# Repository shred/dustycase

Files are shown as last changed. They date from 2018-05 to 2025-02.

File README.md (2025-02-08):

# Particulates Sensor Case

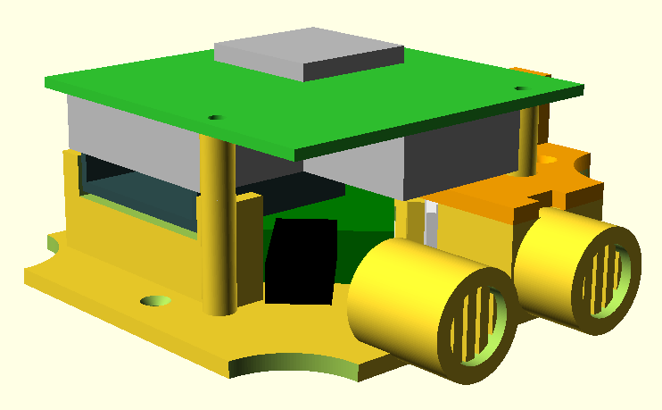
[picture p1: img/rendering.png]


This is a frame for a [luftdaten.info](https://luftdaten.info) compatible particulates sensor.

The original sensor is housed in drain pipes, which is cheap, but also looks quite like that. ;-)

This construction uses an OBO Bettermann T60 junction box, which looks nicer, and is also UV resistant and IP66 water protected. All components are mounted on the printed frame and fixed inside the junction box. Two wind pipes at the bottom of the box allow air flow. A printed tunnel guides the inlet air to the sensor, so there is no need for a hose. Grilles in the wind pipes keep insects from crawling into the box.

A DHT22 temperature and humidity sensor is required for this construction. It is placed at the wall of the inlet air tunnel, so it is protected from rain, but still exposed to the outside air. There is a space for an optional BMP180 air pressure sensor.

Also see the [project page at the PrusaPrinters community](https://www.prusaprinters.org/prints/79784-particulates-sensor-case) for more photos and downloadable STL files.

## Usage

The [frame.scad](./frame.scad) file contains the source code of the construction. You can edit it with [OpenSCAD](http://www.openscad.org/).

## Contribute

* Fork the [Source code at Codeberg](https://codeberg.org/shred/dustycase). Feel free to send pull requests.
* Found a bug? [File a bug report!](https://codeberg.org/shred/dustycase/issues)

## License

This project is licensed under the [Creative Commons - Attribution - Non-Commercial - Share Alike](http://creativecommons.org/licenses/by-nc-sa/3.0/) license.

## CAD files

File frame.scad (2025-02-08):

/*
 * Frame for mounting an SDS011 dust sensor and a NodeMCU into an
 * OBO Bettermann T60 box.
 *
 * (C) 2018 Richard "Shred" Körber
 *
 * Source code:
 *   https://codeberg.org/shred/dustycase
 *
 * Project page at PrusaPrinters:
 *   https://www.prusaprinters.org/prints/79784-particulates-sensor-case
 *
 * Licensed under Creative Commons BY-NC-SA:
 *   https://creativecommons.org/licenses/by-nc-sa/3.0/
 */



// Renders dummy components if set to true.
// Always set to false before exporting STL files!
DEBUG = true;



/* ==== CONFIGURATION ======================================================= */
// This part contains constants that are used for construction. They are not
// consequently used yet, so you might get a broken piece of plastic junk if
// you change any values.

// --- Platter Size ---
length              = 89.0;     // Maximum platter width
length_short        = 60.0;     // Length of each platter edge
thickness           =  3.0;     // Thickness of the platter
mounthole_radius    = 73.0 / 2; // Radius of mounting holes

// --- Inlet Pipes ---
// The T60 box is sold with M25 plug-in seals. If you cut them back to the outer
// ring (D6), a 19mm diameter pipe will fit into the seal. There is a distance
// of 32mm between two seals.
pipe_endFromCenter  = 57.0;     // Distance from box center to end of pipe
pipe_distance       = 32.0;     // Distance between the center of the pipes
pipe_length         = 15.0;     // Pipe length
pipe_extend_l       =  5.0;     // Additional length of left pipe
pipe_diameter       = 19.0;     // Diameter of the pipes

// --- Screws Holes ---
screw               =  3.0;     // Diameter of screw holes for piercing
screwhead           =  5.5;     // Diameter of screw heads
screwlength         = 10.0;     // Screw length
screwhole           =  3.0;     // Diameter of screw holes for mounting
screwcorners        =  5;       // Number of lines a screw hole consists of

// --- DHT22 Dimensions ---
dht22_height        = 15.5;     // Width
dht22_extra         =  1.3;

// --- MCU Dimensions ---
mcu_length          = 52.0;     // Distance between mounting holes, long edge
mcu_width           = 25.0;     // Distance between mounting holes, short edge

// --- SDS011 Dimensions ---
inlet_pos           = 70/2 - 20; // 70mm total, pipe 20mm from edge
inlet_hoseInnerDiam =  6.0;     // Inner diameter of inlet hose
inlet_diam          =  7.2;     // Inlet pipe diameter
inlet_maxOuterDiam  =  9.0;     // Maximum outside diameter of inlet hose
inhaust_len         = 17.0;     // Length of inlet pipe
sensorDist          = 37.0 - 2.0; // Distance from bottom plate to sensor PCB



/* ==== MAIN PARTS ========================================================== */
// For printing, alternately comment out each part, then render and export the
// STL file. (Remember to turn off DEBUG.)

// Renders the bottom part
lowerPart();

// Renders the top part
upperPart();



/* ==== NO USER SERVICABLE PARTS BELOW ;-) ================================== */

// Do some calculations...

length_platter = length - pipe_distance - pipe_diameter + dht22_extra/2;


/* ==== DUMMY COMPONENTS ==================================================== */

/*
 * Renders a DHT22 (temperature and humidity sensor).
 */
module dummy_DHT22() {
    color("white") translate([0, 0, 1.7/2]) difference() {
        union() {
            cube([25.1, 15.1, 1.7], center=true);
            translate([-(5.1/2), 0, 6/2]) cube([20.0, 15.1, 7.7], center=true);
        }
        translate([10.0 - 0.75 + 0.5, 0, -1]) {
            cylinder(d=3.0, h=7.7);
        }
    }
}

/*
 * Renders a Lolin NodeMCU.
 */
module dummy_NodeMCU() {
    translate([0, 14.0, 0]) {
        color("Green") {
            cube([31.25, 57.5, 13], center=true);
        }
        color("Black") rotate([0, 0, 90]) translate([-41, 0, -5]) {
            cube([25.0, 11, 7], center=true);
        }
    }
}

/*
 * Renders an SDS011 (particulates sensor).
 */
module dummy_SDS011() {
    // PCB
    color("LimeGreen") translate([0, 0, 1.0]) {
        difference() {
            cube([70.0, 70.0, 2.0], center=true);
            translate([30.0, 24.0, -1.5]) cylinder(d=3.2, h=3.0);
            translate([-30.0, 24.0, -1.5]) cylinder(d=3.2, h=3.0);
            translate([-11.0, -31.0, -1.5]) cylinder(d=3.2, h=3.0);
        }
    }

    // sensor box
    color("Silver") translate([0, 0, 2.0 + 6.0 - 0.1]) {
        difference() {
            translate([0, -2.5, 0]) cube([66.0, 58.0, 12.0], center=true);
            translate([30.0, 24.0, -2.0]) cube([8, 8, 18.0], center=true);
            translate([-30.0, 24.0, -2.0]) cube([8, 8, 18.0], center=true);
            translate([-21.0, -21.0, -2.0]) cube([26, 24, 18.0], center=true);
        }
        translate([-(70/2-20), 26, -1]) rotate([-90, 0, 0]) difference() {
            union() {
                intersection() {
                    cylinder(10.0, d=inlet_hoseInnerDiam);
                    cylinder(10.0, d1=inlet_hoseInnerDiam*1.5, d2=inlet_hoseInnerDiam*0.9);
                }
                translate([0, 0, 10.0 * 0.75 - 1])
                    cylinder(1, d1=inlet_hoseInnerDiam+0.8, d2=inlet_hoseInnerDiam);
                translate([0, 0, 10.0 * 0.50 - 1])
                    cylinder(1, d1=inlet_hoseInnerDiam+0.8, d2=inlet_hoseInnerDiam);
            }
            translate([0, 0, -0.25]) cylinder(10.0 + 0.5, d=4.0);
        }
    }

    // fan
    color("DarkSlateGray") translate([0, 0, 2.0 + 12.0 + 4.0 - 0.2]) {
        difference() {
            translate([13, -13, 0]) cube([35.0, 35.0, 8.0], center=true);
            translate([13, -15, -2.0]) cube([32.0, 32.0, 8.0], center=true);
        }
    }

    // shielding
    color("Silver") translate([0, 0, -1.75 + 0.1]) {
        translate([13.0, 11.0, 0]) cube([26.0, 26.0, 3.5], center=true);
    }
}



/* ==== LOWER PART ========================================================== */

/*
 * Lower Part materials to be added.
 */
module lowerPartAdd() {
    // base plate
    cube([length, length, thickness], center=true);

    // bolts for dust sensor
    rotate([0, 180, 90]) mirror([0, 0, 1]) {
        diam = 6.0;
        translate([-30.0, 24.0, -1.5]) cylinder(d=diam, h=sensorDist);
        translate([-11.0, -31.0, -1.5]) cylinder(d=diam, h=sensorDist);
    }

    // bolts for OpenMCU
    rotate([0, 180, 45]) translate([14.0, 0, 0]) mirror([0, 0, 1]) {
        dist = 9.0;
        diam = 6.0;
        translate([ mcu_length/2,  mcu_width/2, -thickness / 2]) cylinder(d=diam, h=dist);
        translate([-mcu_length/2,  mcu_width/2, -thickness / 2]) cylinder(d=diam, h=dist);
        translate([ mcu_length/2, -mcu_width/2, -thickness / 2]) cylinder(d=diam, h=dist);
        translate([-mcu_length/2, -mcu_width/2, -thickness / 2]) cylinder(d=diam, h=dist);
    }

    // bolts for BMP180
    translate([13.0, -45, 0]) rotate([0, 0, 90]) {
        dist = 6.0;
        diam = 6.0;
        bmpl = 14.5 / 2;
        bmpw = 9.0 / 2;
        translate([bmpl,  bmpw, thickness / 2]) cylinder(d=diam, h=dist);
        translate([bmpl, -bmpw, thickness / 2]) cylinder(d=diam, h=dist);
    }

    // inlet pipes
    {
        translate([0, pipe_endFromCenter - pipe_length, (pipe_diameter - thickness) / 2]) rotate([-90, 0, 0]) {
            translate([-pipe_distance / 2, 0, 0]) cylinder(pipe_length, d=pipe_diameter);
            translate([pipe_distance / 2, 0, -pipe_extend_l]) cylinder(pipe_length + pipe_extend_l, d=pipe_diameter);
        }
    }

    // wind tunnel
    {
        difference() {
            linear_extrude(height=(dht22_height + thickness/2)) polygon([
                [-(pipe_distance - pipe_diameter - dht22_extra)/2, length/2],
                [-(pipe_distance - pipe_diameter - dht22_extra)/2, 25.0],
                [-(length/2 - 10.0), 8.0],
                [-(length/2), 8.0],
                [-(length/2), 20.0],
                [-(length/2), length/2],
                [-(pipe_distance + pipe_diameter - dht22_extra)/2, length/2],
            ]);
            linear_extrude(height=(dht22_height + thickness/2 + 0.5)) polygon([
                [-(pipe_distance - pipe_diameter)/2 - 3.0, length/2 - 5.0],
                [-(pipe_distance - pipe_diameter)/2 - 3.0, 33.0],
                [-(length/2 - 10.0), inlet_pos - inlet_diam/2],
                [-(length/2 - 3.0), inlet_pos - inlet_diam/2],
                [-(length/2 - 3.0), inlet_pos + inlet_diam/2],
                [-(length/2 - 10.0), inlet_pos + inlet_diam/2],
                [-(pipe_distance + pipe_diameter)/2 + 3.0, 27.0],
                [-(pipe_distance + pipe_diameter)/2 + 3.0, length/2 - 5.0],
            ]);
        }
    }
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

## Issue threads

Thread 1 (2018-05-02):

DHT22 temperature reading is too high

shred, 2018-05-02:
There are reports that the DHT22 temperature is about 3°C higher than a temperature measured by other outdoor thermometers.

It seems that the sensor is too well isolated inside the case, and not sufficiently surrounded by the air inside the wind tunnel.

A solution may be to place the sensor as close to the outside of the air inlet as possible, or even outside of the case.

mrueg, 2018-09-07:
I'm seeing this issue as well. It seems to be worse on the position of the optional BMP and not a static offset.
```
"Real" temperature 19.80
DHT22 temperature 23.20
BMP180 temperature 24.90
```

mach0, 2019-02-06:
it seems that the BMP180 is showing a higher temperature anyway, see:
http://www.kandrsmith.org/RJS/Misc/Hygrometers/calib_many.html

but still there should be more airflow inside the case.
Has anyone a solution for that?

shred, 2019-02-26:
Thank you for the link!

The BMP180 was meant to be a barometer sensor only, with an added thermometer as bonus. The DHT22 was supposed to be the main sensor.

I must confess that I am somewhat disappointed of the DHT22's accuracy in the printed frame. I was hoping that the air taken in by the particulates sensor was sufficient for accurate temperature and humidity readings, but it turned out that the temperatures are always about 3°C too high, and the humidity is adapting to changes very slowly.

I was contacted by someone who planned to put the DHT22 outside of the case, but never heard back about the results.

The DHT22 doesn't look very weather proof to me, so I prefer to keep it inside the case anyway. Maybe it should be mounted closer to the outside of the intake pipe? Maybe it's also a problem that its back and its sides are covered by the printed frame, which may work as a thermal insulation.

I am also pondering about removing the DHT22 altogether, and replacing it with a BME280 (combined thermometer, hygrometer, and barometer) that is mounted as close to the outside as possible.

However I can't do much about it at the moment, as the 3D printer I have access to is broken. :cry:

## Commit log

2018-05-02 First import
    [frame.scad]
2021-10-15 Move project to PrusaPrinters
    [frame.scad]
2025-02-08 Move to Codeberg
    [frame.scad]
